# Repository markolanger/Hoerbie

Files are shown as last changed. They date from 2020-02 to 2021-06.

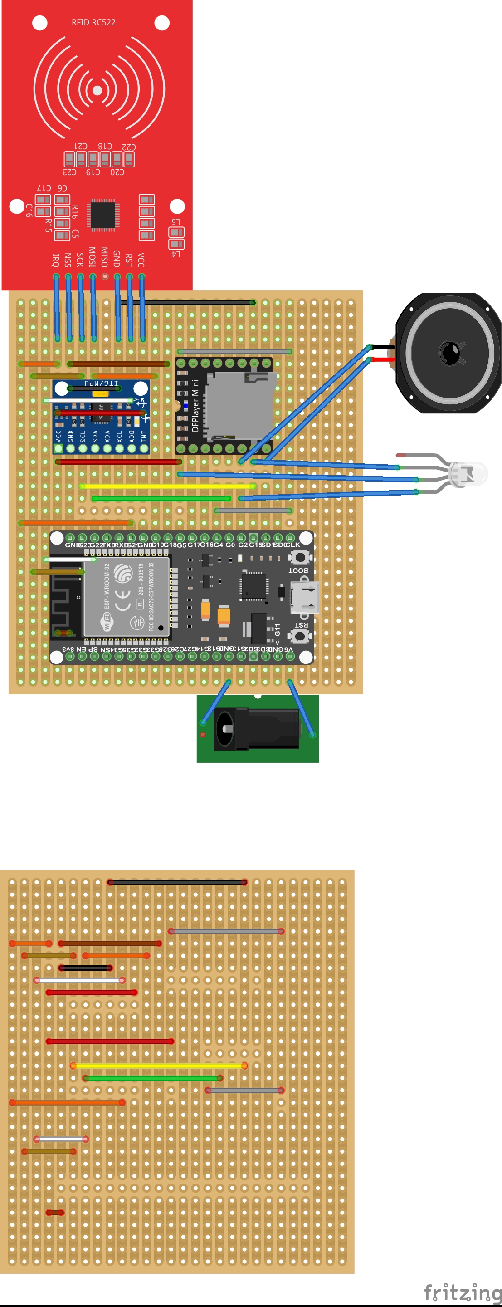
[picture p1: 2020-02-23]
Drawings/hoerbie_Steckplatine.jpg

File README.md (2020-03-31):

# Hoerbie
Hoerbie - Audiobook

# Bedienungsanleitung:

Zubehör: USB-Kabel, 5 TAG's, davon einer bereits bespielt (farbig)
Stromversorgung: USB, 5V, 2A
Eingesetzter TAG: Mifare clasic 1k
SD-Speicherkarte: max. 32GB (99Ordner; 999 Dateien pro Ordner), FAT32

Bitte den Hoerbie mit dem mitgelieferten Kabel und einem USB-Ladegerät (z.B. vom Handy) mit Spannung versorgen. 
Hoerbie benötigt typischerweise 5V und ca. 1A. 

LED Rot; Warnsignal: Ein WLAN Fehler liegt vor
Hoerbie konnte kein bekanntes WiFi finden und startet ein eigenes WiFi. 
Bitte mit dem Wifi Access Point "Hoerbie_Setup" verbinden und im Browser 
http://hoerbie.local oder http://192.168.4.1 eingeben. 
Nun die SSID und Passwort des eigenen WLAN-Netzwerks hinterlegen. 
Auf "Speichern" klicken. Der Hoerbie sollte danach neu gestartet werden.

LED Blau; Begrüßungsmelodie: Hoerbie ist bereit
Nun kann ein TAG aufgelegt werden, die Titelnummer wird angesagt, 
der Titel spielt gem. der TAG Einstellungen. 

Kippsteuerung: wenn der Würfel min. 45° gekippt wird, können Funktionen ausgelößt werden.
Pause/Play: Bewegung in Richtung Lautsprecher beziehungsweise nach vorn. Der Hoerbie muss dannach in die Normalstellung gebracht werden um den Play/Pausebefehl erneut auszulößen.
Weiter: nach rechts, nächster Titel (Spulen im Titel ist nicht möglich)
Zurück: nach links, vorheriger Titel (Spulen im Titel ist nicht möglich)

Drehsteuerung: durch Drehen kann die Lautstärke von Hoerbie angepasst werden. Die Lautstärke kann bis zu dem von den Eltern vorgegebenen maximalen Wert (im WiFi Setup s.u.) verstellt werden. 
Nach jeder Stufe wird die aktuelle Lautstärke als Zahl ausgegeben. Die Drehung muss zügig erfolgen. 

Wenn die Spannungsversorgung unterbrochen wird ist die maximale Lautstärke und aktuelle Lautstärke
auf den Standardwert zurückgesetzt.

Wifi Setup:
Das Setup kann via der vom dhcp vergebenen IP-Adresse (diese kann im Router nachgelesen werden) oder via hoerbie.local abgerufen werden. Die Einstellungen sind weitestgehend selbsterklärend.
Neuen TAG anlernen: Neuen TAG auf den Hoerbie legen, im Setup (http://hoerbie.local) im Untermenü die entsprechenden Auswahlen treffen (Wiedergabemodus, OrdnerID, Datei, Farbe der LED; LED Farben sind vorgegeben) danach auf Speichern klicken. Die Würfel LED wird ROT, dann den zu beschreibenden TAG auflegen oder erneut auflegen. Die LED wird, wenn alles geklappt hat, GRÜN. Bitte den TAG nun abheben und nochmals auflegen um die Funktion zu prüfen.

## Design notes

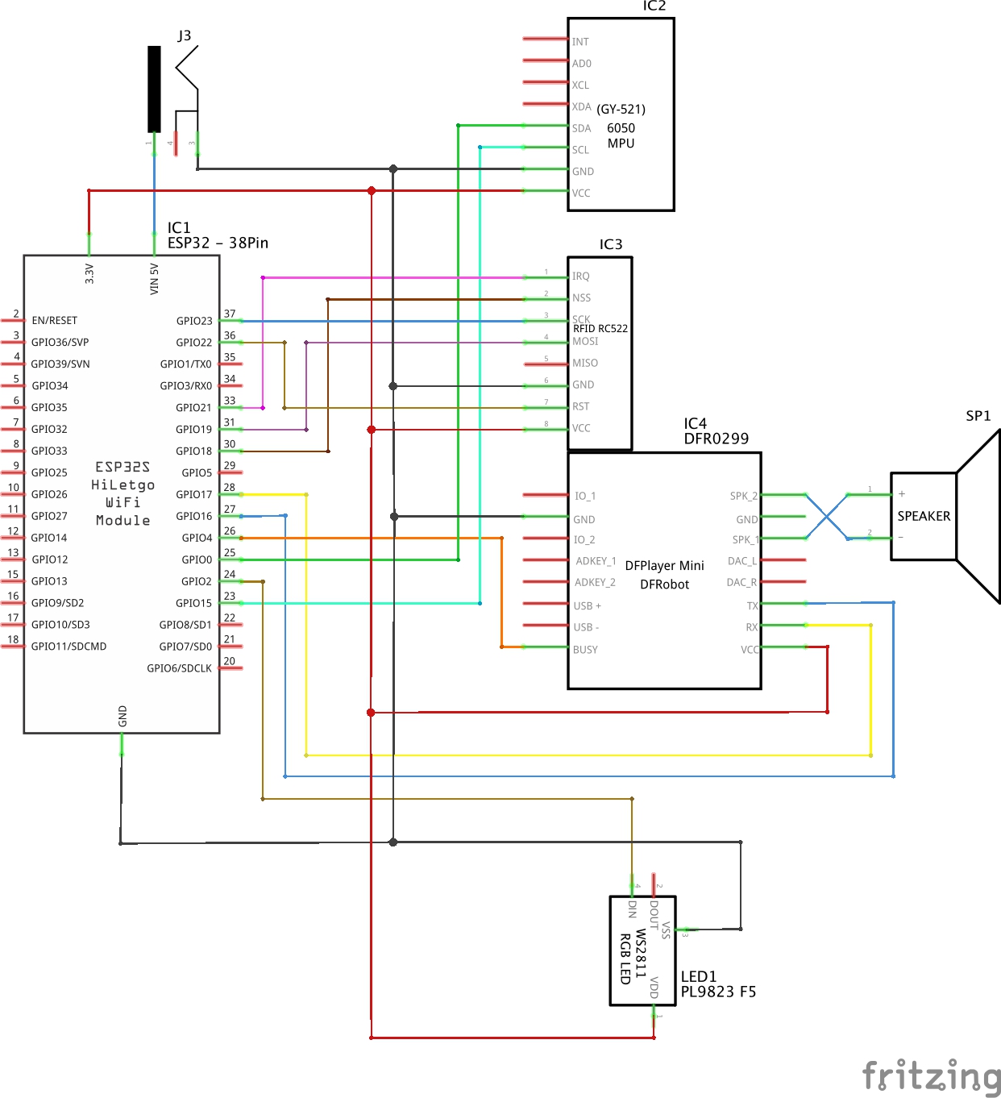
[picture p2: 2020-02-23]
Drawings/hoerbie_Schaltplan.jpg

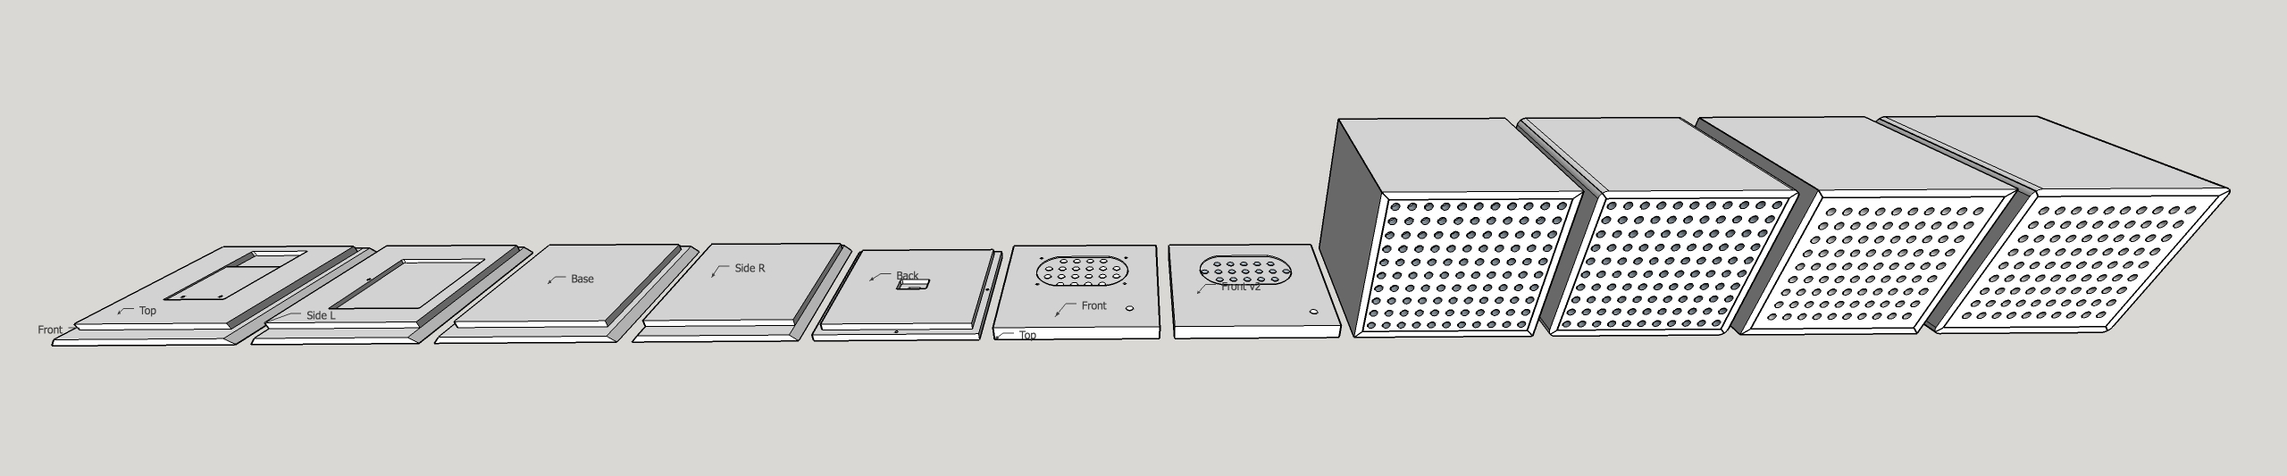
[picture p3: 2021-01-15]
Drawings/3D-Models/Würfel 10mm.jpg

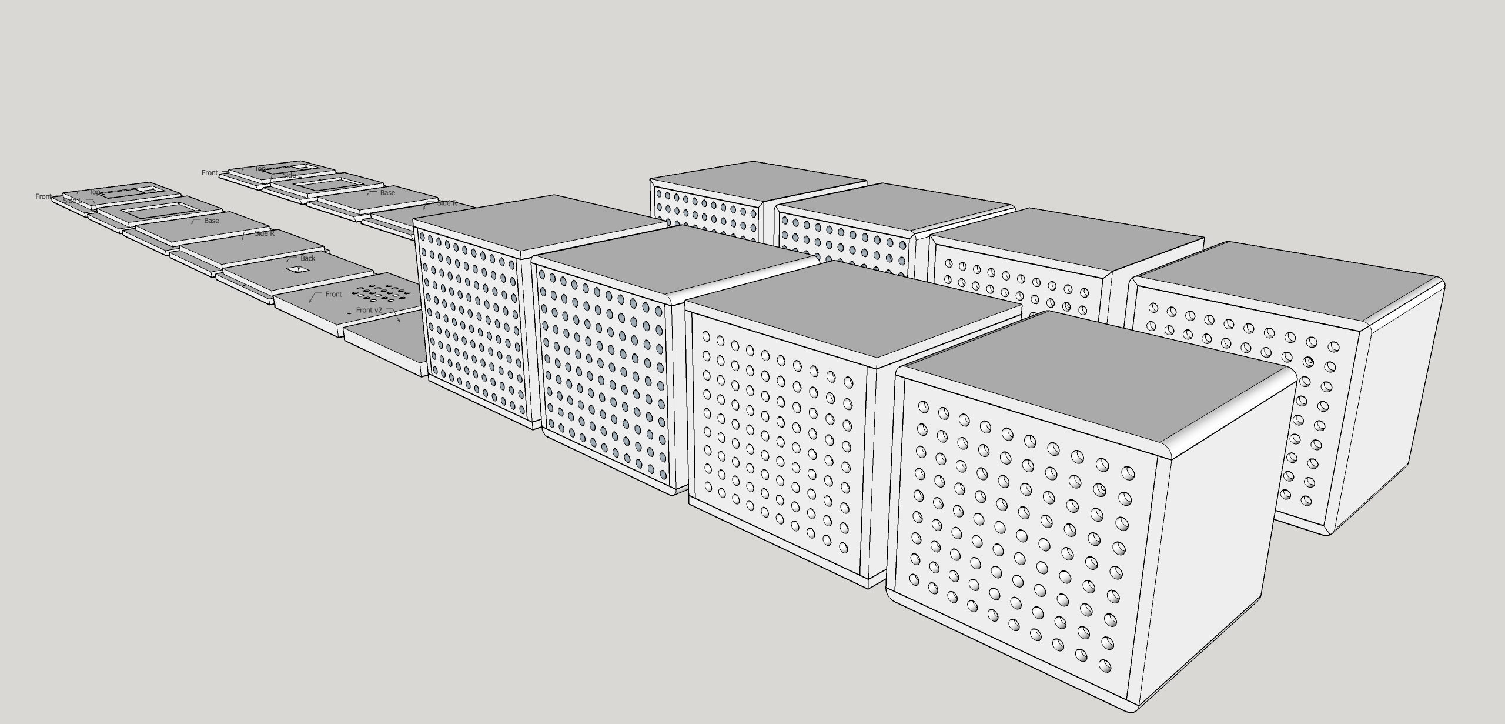
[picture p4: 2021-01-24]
Drawings/3D-Models/Würfel 10mm CNC v2.jpg

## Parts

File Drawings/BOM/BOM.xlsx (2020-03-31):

Bill of Materials:
 | Pricebase: | Sonntag, Februar 23 2020, 21:08:58
Assembly List
Label | Part
IC1 | IC1 ESP32-38 PinWide Generic NodeMCU-32S
IC2 | IC2 InvenSense MPU6050 Variante MPU-6050
IC3 | IC3 RFID RC522
IC4 | IC4 DFRobot | DFPlayer Mini; Bauteilnummer DFR0299
J3 | J3 Power Jack; Typ 5.5mm barrel
LED1 | LED1 RGB LED | PL9823 F5; Bauteilnummer PL9823_F5
SP1 | SP1 SPEAKER | Visaton SC4.7ND 8 Ohm; Bauteilnummer 8048
Shopping List
Amount | Part | Sum: | 41.07 €
1 | ESP32-38Pin NodeMCU-32S |  | 7.66 €
1 | InvenSense MPU6050 |  | 2.85 €
1 | RFID RC522 |  | 5.29 €
1 | DFRobot DFPlayer Mini | DFPlayer Mini; Bauteilnummer DFR0299 | 5.29 €
1 | Power Jack |  | 0.70 €
1 | RGB LED | PL9823 F5; Bauteilnummer PL9823 F5 | 0.70 €
1 | SPEAKER | Visaton SC4.7ND 8 Ohm; Bauteilnummer 8048 | 6.49 €
1 | SD-CARD | Intenso 32GB | 4.90 €
1 | USB-CABLE | LINDY 70267 – Adapterkabel USB A 5,5/2,5mm DC-Hohlstecker | 3.19 €
4 | RFID TAG |  | 4.00 €

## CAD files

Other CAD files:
Drawings/3D-Models/Würfel 10mm CNC.skp

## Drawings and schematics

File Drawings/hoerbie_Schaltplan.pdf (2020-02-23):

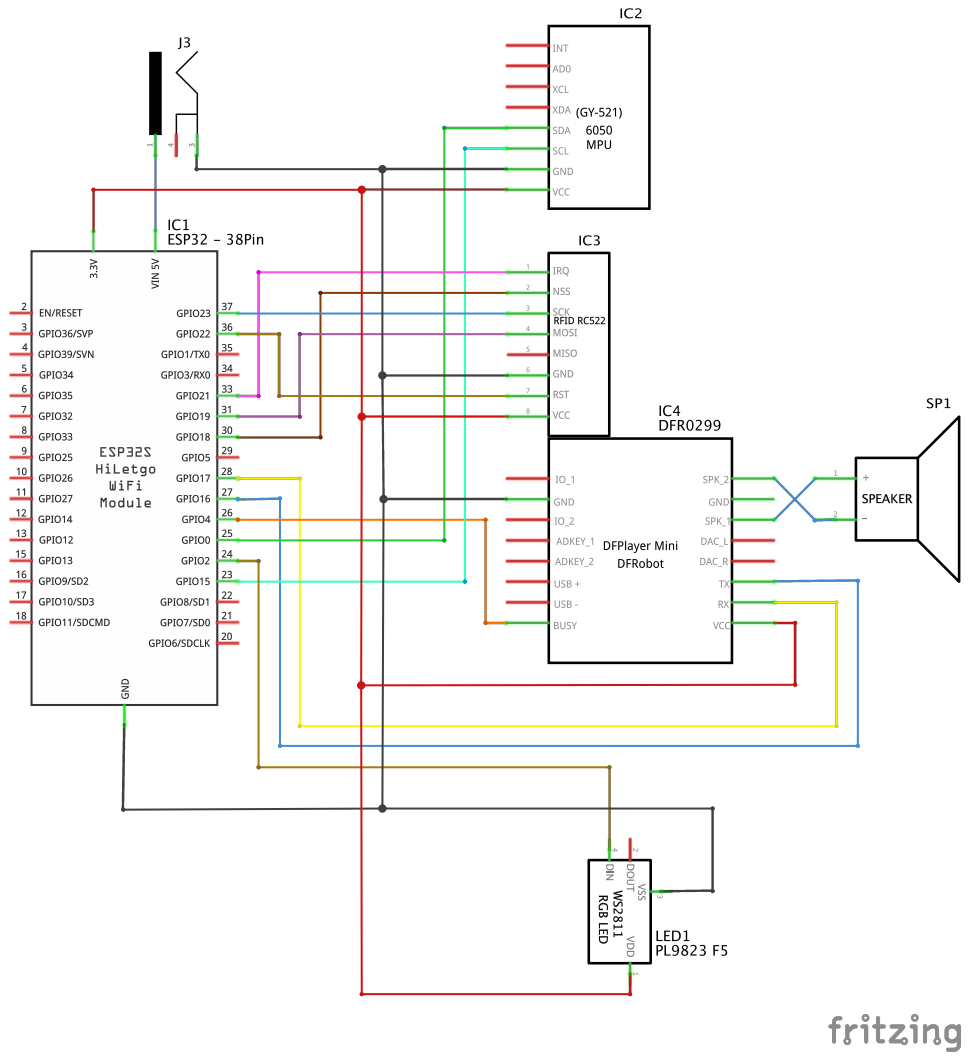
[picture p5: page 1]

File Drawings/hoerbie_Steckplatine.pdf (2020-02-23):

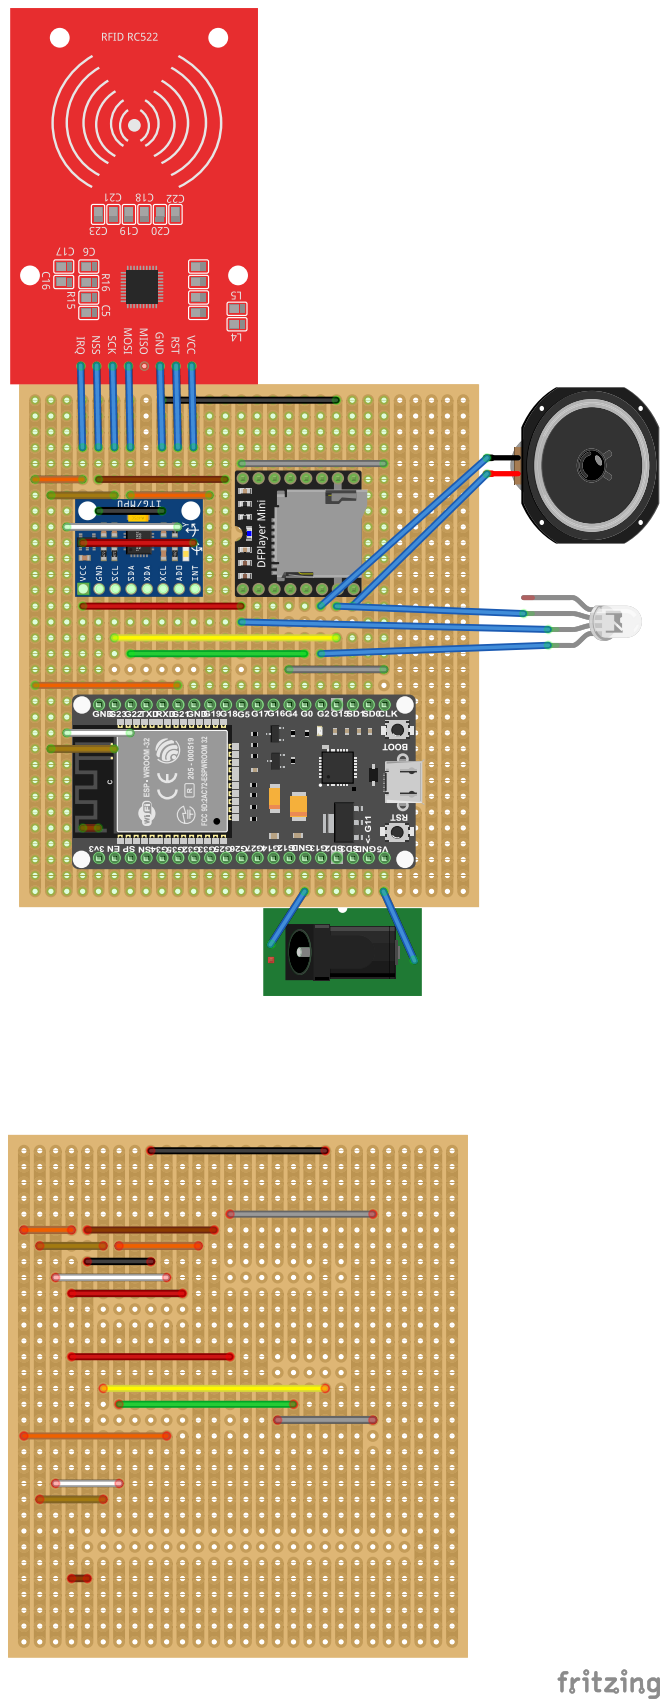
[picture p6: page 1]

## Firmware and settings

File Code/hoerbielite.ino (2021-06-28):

/*========================================================================
  Bibliotheken
  ========================================================================*/
#include <WiFi.h>
#include <WebServer.h>
#include <ESPmDNS.h>
#include <NTPClient.h>
#include <WiFiUdp.h>
#include <Arduino.h>
#include "DFRobotDFPlayerMini.h"
#include <SPI.h>
#include <MFRC522.h>
#include <EEPROM.h>
#include <Preferences.h>
#include "Wire.h"
#include <FastLED.h>

/*========================================================================
  Pinout
  ========================================================================*/

#define ProjectName "Hoerbie"
const int resetPin = 22; // Reset pin NFC
const int ssPin = 21;    // Slave select pin NFC
#define DATA_PIN 2        //WS2812b
#define busyPin 4
//#define headphonePin 25
#define dfpMute 33
unsigned int last_Volume = 20;
unsigned int last_max_Volume = 28;
unsigned int max_Volume = last_max_Volume;
unsigned int akt_Volume = last_Volume;
/*========================================================================
  Debug
  ========================================================================*/

bool            debug = 0; // Auf 1 setzen um debug Informationen über die Serielle Schnittstelle zu erhalten.
bool debugTimeCompare = 0;
bool        debugWifi = 1;
bool        debugBoot = 0;
bool        debugGyro = 0;
bool       debugSetup = 0;
bool         debugLed = 0;
bool      debugWifiAP = 0;
bool             flag = 0;
bool   Hoerspielmodus = 0;

/*========================================================================
  Globale Variablen
  ========================================================================*/
Preferences preferences;
int timeout = 20;


//MPU-6050
const int MPU_addr = 0x68;                              // I2C address of the MPU-6050
int16_t AcX, AcY, AcZ, Tmp, GyX, GyY, GyZ;
int setupAcX = 10000;                                   // Next / Prev
int setupAcY = 15000;                                   // Pause/Config
int setupGyZ = 15000;                                   // Volume


//Webserver
unsigned long last_color = 0xFFFFFF;
int success2 = 0;
int success = 0;
int oldfolder = 1;
String TimerOFF = "00:00";
String TimerON = "00:00";
uint8_t TMR_OFF_HH, TMR_OFF_MM, TMR_ON_HH, TMR_ON_MM;
int TMR_OFF_REP = 0;
int TMR_ON_REP = 0;

bool TMP_OFFTIME = true;
bool TMP_ONTIME = true;
bool WakeUpLight = false;
bool SleepLight = false;
bool startSR = false;


//Sunrise
static uint16_t heatIndex = 0; // start out at 0
DEFINE_GRADIENT_PALETTE( sunrise_gp ) {
  0,     0,   0,   0,   //schwarz
  128,   240,   0,   0,   //rot
  224,   240, 240,   0,   //gelb
  255,   128, 128, 240    //sehr helles Blau
};

volatile uint32_t isrCounter = 0;
volatile uint32_t lastIsrAt = 0;

//NTP
WebServer server(80);
WiFiUDP ntpUDP;
NTPClient timeClient(ntpUDP);


//NFC
// this object stores nfc tag data
struct nfcTagObject {
  uint32_t cookie;
  uint8_t version;
  uint8_t folder;
  uint8_t mode;
  uint8_t special;
  uint32_t color;
};

nfcTagObject myCard;
void resetCard(void);
bool readCard(nfcTagObject *nfcTag);
void setupCard(void);
static void nextTrack();
void startTimer(void);
void stoppTimer(void);
int voiceMenu(int numberOfOptions, int startMessage, int messageOffset, bool preview = false, int previewFromFolder = 0);
bool knownCard = false;
uint16_t numTracksInFolder;
uint16_t track;
MFRC522::MIFARE_Key key;
bool successRead;
byte sector = 1;
byte blockAddr = 4;
byte trailerBlock = 7;
MFRC522::StatusCode status;




//LED WS2812b
#define NUM_LEDS 1        //number of LEDs WS2812b
#define BRIGHTNESS 32     //brightness  (max 254)
#define LED_TYPE WS2812B   // I know we are using ws2812, but it's ok!
#define COLOR_ORDER GRB
CRGB leds[NUM_LEDS];


//Buttons
bool ignorePauseButton = false;
bool ignoreUpButton = false;
bool ignoreDownButton = false;
bool ignoreConfigButton = false;
uint8_t numberOfCards = 0;

/*========================================================================
  Builder
  ========================================================================*/

MFRC522 mfrc522 = MFRC522(ssPin, resetPin); // Create instance
unsigned int Brightness = BRIGHTNESS;
hw_timer_t * timer = NULL;
volatile SemaphoreHandle_t timerSemaphore;
portMUX_TYPE timerMux = portMUX_INITIALIZER_UNLOCKED;

void IRAM_ATTR onTimer() {
  // Increment the counter and set the time of ISR
  portENTER_CRITICAL_ISR(&timerMux);
  isrCounter++;
  lastIsrAt = millis();
  portEXIT_CRITICAL_ISR(&timerMux);
  // Give a semaphore that we can check in the loop
  xSemaphoreGiveFromISR(timerSemaphore, NULL);
  // It is safe to use digitalRead/Write here if you want to toggle an output
}



//DFR MP3========================================================================================================================
class Mp3Notify {
  public:
    static void OnError(uint16_t errorCode) {
      // see DfMp3_Error for code meaning
      Serial.println();
      Serial.print("Com Error ");
      Serial.println(errorCode);
    }
    static void OnPlayFinished(uint16_t track) {
      Serial.print("Track beendet");
      Serial.println(track);
      delay(100);
      nextTrack();
    }
    static void OnCardOnline(uint16_t code) {
      Serial.println(F("SD card online "));
    }
    static void OnCardInserted(uint16_t code) {
      Serial.println(F("SD card ready "));
    }
    static void OnCardRemoved(uint16_t code) {
      Serial.println(F("SD card ejected "));
    }
};
HardwareSerial mySoftwareSerial(2);
DFRobotDFPlayerMini myDFPlayer;
// void printDetail(uint8_t type, int value) {Serial.println(F("Blubberd ")};
// Leider kann das Modul keine Queue abspielen.
static void nextTrack() {
  if (knownCard == false)
    // Wenn eine neue Karte angelernt wird soll das Ende eines Tracks nicht
    // verarbeitet werden
    return;

  if (myCard.mode == 1) {
    Serial.println(F("Hörspielmodus ist aktiv"));;
  }
  if (myCard.mode == 2) {
    if (track >= numTracksInFolder || track < 0) {
      track = 0;
      Serial.println("track zurücksetzten ");
    }
    if (track != numTracksInFolder) {
      track = track + 1;
      myDFPlayer.playFolder(myCard.folder, track);
      flag = 1;
      Serial.print(F("Albummodus ist aktiv -> nächster Track: "));
      Serial.print(track);
    }
    else track = 1;
  }
  if (myCard.mode == 3) {
    track = random(1, numTracksInFolder + 1);
    Serial.print(F("Party Modus ist aktiv -> zufälligen Track spielen: "));
    Serial.println(track);
    flag = 1;
    myDFPlayer.playFolder(myCard.folder, track);
  }
  if (myCard.mode == 4) {
    Serial.println(F("Einzel Modus aktiv"));
  }
  if (myCard.mode == 5) {
    if (track != numTracksInFolder) {
      track = track + 1;
      Serial.print(F("Hörbuch Modus ist aktiv -> nächster Track und "
                     "Fortschritt speichern"));
      Serial.println(track);
      myDFPlayer.playFolder(myCard.folder, track);
      flag = 1;
      // Fortschritt im EEPROM abspeichern
      EEPROM.write(myCard.folder, track);
    } else
      // Fortschritt zurück setzen
      EEPROM.write(myCard.folder, 1);
  }
  delay(500);
}
static void previousTrack() {
  if (myCard.mode == 1) {
    Serial.println(F("Hörspielmodus ist aktiv -> Track von vorne spielen"));
    myDFPlayer.playFolder(myCard.folder, track);
    flag = 1;
  }
  if (myCard.mode == 2) {
    Serial.println(F("Albummodus ist aktiv -> vorheriger Track"));
    if (track != 1) {
      track = track - 1;
    }
    myDFPlayer.playFolder(myCard.folder, track);
    flag = 1;
  }
  if (myCard.mode == 3) {
    Serial.println(F("Party Modus ist aktiv -> Track von vorne spielen"));
    myDFPlayer.playFolder(myCard.folder, track);
    flag = 1;
  }
  if (myCard.mode == 4) {
    Serial.println(F("Einzel Modus aktiv -> Track von vorne spielen"));
    myDFPlayer.playFolder(myCard.folder, track);
    flag = 1;
  }
  if (myCard.mode == 5) {
    Serial.println(F("Hörbuch Modus ist aktiv -> vorheriger Track und "
                     "Fortschritt speichern"));
    if (track != 1) {
      track = track - 1;
    }
    myDFPlayer.playFolder(myCard.folder, track);
    flag = 1;
    // Fortschritt im EEPROM abspeichern
    EEPROM.write(myCard.folder, track);
  }
}
bool isPlaying() {
  return !digitalRead(busyPin);
}



// HTML Functions========================================================================================================================
//Funktion um die Antworten der HTML Seite auszuwerten
void handleRestart() {
  preferences.end();
  ESP.restart();
}
void handleSetup() {
  server.send ( 200, "text/html", SetupPage());
  if (server.args() > 0 ) { // Arguments were received
    for ( uint8_t i = 0; i < server.args(); i++ ) {

      Serial.print("Vom Server wurde folgendes empfangen: "); // Display the argument
      Serial.print(server.argName(i)); // Display the argument
      Serial.print("=");
      Serial.println(server.arg(i));

      if (server.argName(i) == "ssid" ) {
        preferences.clear();
        Serial.print("Speichere SSID: ");
        Serial.println(server.arg(i));
        preferences.putString("SSID", server.arg(i));
      }
      else if (server.argName(i) == "pw") {
        Serial.print("Speichere PW: ");
        Serial.println(server.arg(i));
        preferences.putString("Password", server.arg(i));
      }
    }
  }
}
void httpTimeJson() {
  //  String output = "{ \"uptime\":" + String(millis()); + "\","\"Volumenow\":" + akt_Volume; + " }";
  String output  = "{\"uptime\":\"" + String(millis()) + "\",\"VolumeNow\":\"" + akt_Volume + "\",\"VolumeMax\":\"" + max_Volume + "\",\"Card_Cookie\":\"" + myCard.cookie + "\",\"Card_Serial\":\"" + mfrc522.PICC_ReadCardSerial() + "\",\"Card_Folder\":\"" + myCard.folder + "\",\"Card_Mode\":\"" + myCard.mode + "\",\"Tmp\":\"" + Tmp + "\"}";
  server.send(200, "application/json", output);
}
void httpNotFound() {
  server.send(404, "text/plain", "404: Not found");
}
void handleRoot() {
  server.send ( 200, "text/html", getPage() );
  if (server.args() > 0 ) { // Arguments were received
    for ( uint8_t i = 0; i < server.args(); i++ ) {

      Serial.print("Vom Server wurde folgendes empfangen: "); // Display the argument
      Serial.print(server.argName(i)); // Display the argument
      Serial.print("=");
      Serial.println(server.arg(i));

      if (server.argName(i) == "appt-time-off" ) {

        TimerOFF = server.arg(i);
        char charBuf[TimerOFF.length() + 1];
        TimerOFF.toCharArray(charBuf, TimerOFF.length() + 1);
        TMR_OFF_HH = atof(strtok(charBuf, ":"));
        TMR_OFF_MM = atof(strtok(NULL, ":"));
        Serial.print("Die eingelesene Zeit für TimerOFF: ");
        Serial.print(TMR_OFF_HH);
        Serial.print(":");
        Serial.println(TMR_OFF_MM);
        TMR_OFF_REP = 0;
        TMP_OFFTIME = false;

      }
      else if (server.argName(i) == "cb_tmr_off") {
        TMR_OFF_REP = 1;
        Serial.println("Für den TimerOFF wurde eine Wiederholung eingestellt");
      }
      else if (server.argName(i) == "appt-time-on") {
        TimerON = server.arg(i);
        char charBuf[TimerON.length() + 1];
        TimerON.toCharArray(charBuf, TimerON.length() + 1);
        TMR_ON_HH = atof(strtok(charBuf, ":"));
        TMR_ON_MM = atof(strtok(NULL, ":"));
        Serial.print("Die eingelesene Zeit für TimerON: ");
        Serial.print(TMR_ON_HH);
        Serial.print(":");
        Serial.println(TMR_ON_MM);
        TMR_ON_REP = 0;
        TMP_ONTIME = false;
      }
      else if (server.argName(i) == "cb_tmr_on") {
        TMR_ON_REP = 1;
        Serial.println("Für den TimerON wurde eine Wiederholung eingestellt");
      }
      else if (server.argName(i) == "max_volume") {
        max_Volume = server.arg(i).toInt();
        Serial.println("Die maximale Lautstärke wurde geändert");
      }
      else if (server.argName(i) == "akt_volume") {
        if (server.arg(i).toInt() < max_Volume) {
          myDFPlayer.volume(server.arg(i).toInt());
          delay(200);
          akt_Volume = myDFPlayer.readVolume();
          server.send(200, "text/html", getPage());
        } else if (server.arg(i).toInt() > max_Volume) {
          myDFPlayer.volume(max_Volume);
          akt_Volume = max_Volume;
          myDFPlayer.advertise(902);
          delay(1650);
          myDFPlayer.stopAdvertise();
          delay(40);
          server.send(200, "text/html", getPage());
          Serial.println("!MAXVol+");
        } else
        {
          myDFPlayer.volume(max_Volume);
          akt_Volume = max_Volume;
          myDFPlayer.advertise(902);
          delay(1650);
          myDFPlayer.stopAdvertise();
          delay(40);
          server.send(200, "text/html", getPage());
          Serial.println("!MAXVol+");
        }
        delay(200);
        myDFPlayer.advertise(akt_Volume);
        delay(1400);
        Serial.println("Die aktuelle Lautstärke wurde geändert");
      }
      else if (server.argName(i) == "LED_color") {
        Serial.println("Die Farbe der LEDs wird geändert: " + server.arg(i));
        String Color = server.arg(i);
        Color.remove(0, 1);
        char *ptr;
        char charBuf[Color.length() + 1];
        Color.toCharArray(charBuf, Color.length() + 1);
        unsigned long col = strtol(charBuf, &ptr, 16);
        fill_solid(leds, NUM_LEDS, col); // Farbe aller LEDs ändern
        FastLED.show();
        if (debugLed) {
          Serial.print("Color: ");  //?
          Serial.println(col);
          Serial.println(charBuf);
          Serial.println(Color);
        }
      }
      else if (server.argName(i) == "LED_bri") {
        Serial.println("Die Helligkeit der LEDs wird geändert ");
        Serial.println("Helligkeit = " + server.arg(i));
        FastLED.setBrightness(server.arg(i).toInt());
        FastLED.show();
      }
      else if (server.argName(i) == "cb_SleepLight_on") {
        //CODE HERE
        if (server.arg(i).toInt() == 1) {
          SleepLight = true;
        }
      }
      else if (server.argName(i) == "cb_SleepLight_off") {
        if (server.arg(i).toInt() == 0) {
          SleepLight = false;
        }
      }
      else if (server.argName(i) == "cb_WakeUpLight_on") {
        if (server.arg(i).toInt() == 1) {
          WakeUpLight = true;
        }
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
void loop() {
  Serial.println("Loop");
  do {


    if (xSemaphoreTake(timerSemaphore, 0) == pdTRUE) { //Timer Interrupt Routine
      uint32_t isrCount = 0, isrTime = 0;
      // Read the interrupt count and time
      portENTER_CRITICAL(&timerMux);
      isrCount = isrCounter;
      isrTime = lastIsrAt;
      portEXIT_CRITICAL(&timerMux);
      //Ab hier Funktionen für Timer

      if (success == 1) TimeCompare(); //Abfrage der Zeit im Sekundentakt
      if (startSR == true) sunrise();
    }
    server.handleClient();


//      Serial.print("myDFPlayer.available: ");
//      Serial.print(myDFPlayer.available());
//      Serial.print(" | isPlaying:");
//      Serial.print(isPlaying());
//      Serial.print(" | oldfolder: ");
//      Serial.println(oldfolder);
    


    if (!isPlaying()) {
      if (myDFPlayer.available()) {
        printDetail(myDFPlayer.readType(), myDFPlayer.read()); //Print the detail message from DFPlayer to handle different errors and states.
      }
    }
    if (isPlaying()) {
      if (!flag == 0) {
//        Serial.println("Advertising Track");
//        delay(10);
//        myDFPlayer.advertise(track);
        flag = 0;
      }
    }



    Wire.beginTransmission(MPU_addr);
    Wire.write(0x3B); // starting with register 0x3B (ACCEL_XOUT_H)
    Wire.endTransmission(false);
    Wire.requestFrom(MPU_addr, 14, true); // request a total of 14 registers

    AcX = Wire.read() << 8 | Wire.read(); // 0x3B (ACCEL_XOUT_H) & 0x3C (ACCEL_XOUT_L)
    AcY = Wire.read() << 8 | Wire.read(); // 0x3D (ACCEL_YOUT_H) & 0x3E (ACCEL_YOUT_L)
    AcZ = Wire.read() << 8 | Wire.read(); // 0x3F (ACCEL_ZOUT_H) & 0x40 (ACCEL_ZOUT_L)
    Tmp = Wire.read() << 8 | Wire.read(); // 0x41 (TEMP_OUT_H) & 0x42 (TEMP_OUT_L)
    GyX = Wire.read() << 8 | Wire.read(); // 0x43 (GYRO_XOUT_H) & 0x44 (GYRO_XOUT_L)
    GyY = Wire.read() << 8 | Wire.read(); // 0x45 (GYRO_YOUT_H) & 0x46 (GYRO_YOUT_L)
    GyZ = Wire.read() << 8 | Wire.read(); // 0x47 (GYRO_ZOUT_H) & 0x48 (GYRO_ZOUT_L)

    //    if (debugGyro) {
    //      Serial.print("AcX = "); Serial.print(AcX);
    //      Serial.print(" | AcX = "); Serial.print(AcX);
    //      Serial.print(" | AcZ = "); Serial.print(AcZ);
    //      Serial.print(" | Tmp = "); Serial.print(Tmp / 340.00 + 36.53); //equation for temperature in degrees C from datasheet
    //      Serial.print(" | GyX = "); Serial.print(GyX);
    //      Serial.print(" | GyY = "); Serial.print(GyY);
    //      Serial.print(" | GyZ = "); Serial.print(GyZ);
    //      Serial.print(" | Tmp = "); Serial.println(Tmp / 340.00 + 32.53);
    //    }
    if (AcX > setupAcX && ignoreUpButton == 0) {
      ignoreUpButton = 1;
      if (debugGyro) {
        Serial.print("Left: Locked | AcX = ");
        Serial.println(AcX);
      }
      Serial.println(F("previousTrack"));
      previousTrack();
    }
    if (AcX < (setupAcX / 2) && AcX > 1 && ignoreUpButton == 1) {
      ignoreUpButton = 0;
      delay(10);
      if (debugGyro) {
        Serial.print("Left: Unlocked | AcX = ");
        Serial.println(AcX);
      }
    }
    if (AcX < (setupAcX * -1) && ignoreDownButton == 0) {
      ignoreDownButton = 1;
      if (debugGyro) {
        Serial.print("Right: Locked | AcX = ");
        Serial.println(AcX);
      }
      Serial.println(F("nextTrack"));
      nextTrack();
    }
    if (AcX > ((setupAcX * -1) / 2) && AcX < -10 && ignoreDownButton == 1) {
      ignoreDownButton = 0;
      delay(10);
      if (debugGyro) {
        Serial.print("Right: Unlocked | AcX = ");
        Serial.println(AcX);
      }
    }
    if (AcY < (setupAcY * -1) && ignorePauseButton == 0) {
      ignorePauseButton = 1;
      if (debug) {
        Serial.print("Forward: Locked | AcY = ");
        Serial.println(AcY);
      }
      if (isPlaying()) {
        myDFPlayer.pause();
        Serial.println("Pause");
      }
      if (!isPlaying()) {
        myDFPlayer.start();
        Serial.println("Start");
      }
    }
    if (AcY > ((setupAcY * -1) / 2) && AcY < -10 && ignorePauseButton == 1) {
      ignorePauseButton = 0;
      if (debugGyro) {
        Serial.print("Forward: Unlocked | AcY = ");
        Serial.println(AcY);
      }
    }
    if (GyZ > setupGyZ) {
      if (myDFPlayer.readVolume() <= max_Volume) {
        delay(200);
        myDFPlayer.volumeUp();
        delay(200);
        akt_Volume = myDFPlayer.readVolume();
        Serial.print("volumeUp | akt_Volume: ");
        Serial.println(akt_Volume);
        delay(200);
        myDFPlayer.advertise(akt_Volume);
        delay(200);
        if (debugGyro) {
          Serial.print("volumeUp | GyZ = ");
          Serial.println(GyZ);
        }
      }



      if (myDFPlayer.readVolume() > max_Volume) {
        myDFPlayer.volume(max_Volume);
        akt_Volume = max_Volume;
        myDFPlayer.advertise(902);
        delay(1650);
        myDFPlayer.stopAdvertise();
        delay(300);
        myDFPlayer.advertise(akt_Volume);
        if (debugGyro) {
          Serial.print("Volume at max!: ");
          Serial.println(myDFPlayer.readVolume());
        }
      }
    }


    if (GyZ < (setupGyZ * -1)) {
      if (myDFPlayer.readVolume() != 0) {
        myDFPlayer.volumeDown();
        myDFPlayer.volumeDown();
        delay(50);
        akt_Volume = myDFPlayer.readVolume();
        myDFPlayer.advertise(akt_Volume);
        delay(200);
        if (debugGyro) {
          Serial.print("volumeDown | GyZ = ");
          Serial.println(GyZ);
        }
      }
    }

  } while (!mfrc522.PICC_IsNewCardPresent()); //wenn keine RFID Karte aufgelegt wurde

  // --> RFID Karte wurde aufgelegt

  if (!mfrc522.PICC_ReadCardSerial())
    return;

  if (readCard(&myCard) == true) {
    if (myCard.cookie == 322417479 && myCard.folder != 0 && myCard.mode != 0) {

      knownCard = true;
      myDFPlayer.readFileCountsInFolder(myCard.folder);
      numTracksInFolder = myDFPlayer.readFileCountsInFolder(myCard.folder);

      Serial.print("num Tracks Folder: ");
      Serial.print(numTracksInFolder);
      Serial.print(" | myCard.mode: ");
      Serial.println(myCard.mode);
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

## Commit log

2020-03-01 Create Bill of Materials
2020-03-01 Rename Bill of Materials to Drawings/BOM/Bill of Materials
2020-03-31 Update hoerbie_v1.0.ino
    bug fix
    [hoerbie_v1.0.ino]
